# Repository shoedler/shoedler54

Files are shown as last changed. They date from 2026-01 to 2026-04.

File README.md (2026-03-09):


> Kailh Choc v2 Ice Creams, Taihao THTs

# shoedler54
A 54-key, column-staggered, ortholinear, wireless split keyboard, inspired by ZSA Voyager and silakka54.
Designed for Mx-spacing (18mm keycaps) and 1350 Choc v1 or v2 switches.

## Why?

This project came to life as I wanted to get up to speed with [ergogen.xyz](ergogen.xyz). The main goal of was to build a keyboard using solely the declarative ergogen paradigm - including making a case. As such, the only thing that was done outside of ergogen was to route the PCB and flip one case half in the slicer. That, as well as configuring the firmware (it'd be a nice extension to ergogen to generate the `.dtsi` file for ZMK automatically, but alas, that's not supported - yet).
Other things I've aimed for:
- Must be cheap, < $100 for a complete keyboard.
- Must be low profile, comparable to the ZSA Voyager.

## Impressions


> Carry case


> With optional MCU + battery cover


> Black version with Kailh Choc v2 Black Clouds, Repo-included 3D printed keycaps

---

## Bill of materials

For one complete board - e.g. two halves - you'll need:

- 2 Promicro NRF52840
- 54 1N4148W SOD-123 Diodes
- 54 Kailh Low-profile 1350 Hotswap Sockets
- 54 Keyswitches, Choc v1 or v2
- 54 1u (18mm) Keycaps, Choc v1 or v2 stems (I suggest to print the provided ones (Mx-stem e.g. Choc v2), or - if you want legends, the Taihao THTs)
- 2 EVQPUL02K Switches ($\to$ board reset button)
- 2 SSSS811101 Switches ($\to$ power switch)
- 2 801540 3.7v, 380mAh Batteries
  - or, 2 701535 3.7v, 350mAh
  - or, 2 501646 3.7v, 380mAh (these are too long (46mm) and require to be soldered to the JST pads, which I **do not recommend**!)
- 2 JST PH 2.0 THT Sockets

For the case you'll need:

- Obviously, the printed case files. See section about printing below.
- 10x M2x5 (or 6)mm flathead screws
- 10x M2x3mm Heat set inserts
- Optionally, some painters tape.

## Approximate cost

| What | Supplier | Comment | Price |
| --- | --- | --- | --- |
| 2 PCBs | JLCPCB | 5pcs. (min), including a hefty delivery fee to get to my location, $32 | ~$13 |
| 2 MCUs | AliExpress | Promicro NRF52840 | ~$4 |
| 54 Diodes | AliExpress | 1N4148W SOD-123 | ~$1 |
| 54 Kailh Low 1350 Sockets | AliExpress | Hotswap | $4 |
| 54 Keyswitches, Choc v1/v2 | AliExpress | pack of 70 | $25 |
| 54 1u Keycaps, Choc v1/v2 | AliExpress | pack of 60 | $15 |
| 2 Reset Switches | AliExpress | EVQPUL02K | ~$1 |
| 2 Power Switches | AliExpress | SSSS811101 | $1 |
| 2 Batteries | AliExpress | 801546, 380mAh | $8 |
| 2 JST PH 2.0 Sockets | AliExpress | | ~$1 |
> Prices as of january, 2026

Should result in ~$75 per completed keyboard. This does not include the case hardware and printed case files, but it's all you need to get a working keyboard. Also, the prices listed are adjusted to the amount of parts required.

> [!NOTE]
> You'd want to buy some parts in "bulk", like a strip of 100 diodes. Since you likely also have a minimum order quantity for the PCBs, it might make sense to buy two more MCUs and maybe some old keyswitches and caps to get another full keyboard out of the rest of the parts and still have one PCB for soldering mistakes left ;)

As alluded to in the BOM, a 3d printable model for a custom cap that fits this build is provided - more on that in the build guide.

## Build guide

### PCB manufacturing

> PCB related files are located in the `kicad` directory.

Assuming you have ordered the parts and don't want to route the PCB yourself, there's premade gerber archive located at `kicad/gerber.zip` which you can use. I've used JLCPCB, default settings (1.6mm two layer PCB) and with the black solder mask.

### Printing the case

> Case files are located in the `stl` directory.

I used a Babulab A1 mini and default slicer settings (Bambustudio). Everything was printed in their PLA Matte.

#### What do I need to print?

You'll need at least:

- 2x `shoedler54_switchplate_right.stl`, which is the plate that sits on the PCB and where the keyswitches are mounted into - I recommend using the provided 3mf files for that: `shoedler54_switchplate_left.3mf` and `shoedler54_switchplate_right.3mf`. That'll give you mirrored versions so you have the buildplate-finish texture on the same side for both halves.
- 2x `shoedler54_case_left.stl`, which is the case where the PCB gets mounted in - same story, use the provided 3mf files for that: `shoedler54_case_left.3mf` and `shoedler54_case_right.3mf`. That'll also give you mirrored versions for both halves with fuzzy skin. Theoretically, you don't **need** the case, but I strongly recommend it to provide a little bit of protection for the PCB. If you're working directly with the stl, then you'll have to mirror it. I suggest using the fuzzy skin setting (in Bambustudio: `Others > Special mode > Fuzzy skin`, use "Contour").

Optional:

- 2x `shoedler54_case_cover_right.stl`, which is a small cover for the MCU + battery. Use `shoedler54_case_cover_left.3mf` and `shoedler54_case_cover_right.3mf` for mirrored version. Same as with the case, if you're working with the stl directly you'll need to mirror this too.
- 1x `shoedler54_carry_case.stl`, which is a Go60-ish carry shell for the shoedler54. Use `shoedler54_carry_case.3mf` for a version with fuzzy skin. I did manage to print it without support, but there's a bit of luck involved.

### Printing the keycaps

> Keycap related files are located in the `scad` directory.

The caps require no supports if you place them on one of the fillets - they do however require good bed adhesion. This, just like the case, was also printed on a Bambulab A1 mini with PLA Matte. Also, like the case, I've provided a 3mf file to print 26 regular + 1 indexing (F/J keys on QWERTY) keys. If you have to use the stl directly:

- Use 0.12mm layer height (including the initial layer).
- Use a brim - if your slicer doesn't automatically generate it, add it manually.

> [!NOTE]
> The keycap was designed in [OpenSCAD](openscad.org). It's fully parametrized, so it's easy to adapt to your liking.

### Soldering

Since the PCB is reversible it can get confusing quick. All of the components **except the ProMicro and the JST connector** are soldered to the backside of each half.

1. Solder diodes, hotswap sockets, reset- and powerswitches on the backside of each half. **This is also the side were you bridge all of the solder-jumpers with solder** (8 for the Mcu, 2 for the Battery connector).
2. Direct-solder the ProMicro to the frontside of the PCB, along with the JST connector. (Pin Sockets are also an option for the mcu, if you want - it just makes the keyboard a bit thicker)

> [!CAUTION]
> Before you continue it's a good idea to verify that there's no short between the JSTs +/- terminal as well as the ProMicros VCC and GND.

I suggest to load the firmware next and check that everything works before assembly.

### Loading the ZMK firmware

> Firmware related files consist of: config/, boards/, zephyr/ directories, as well as the build.yml file and the GitHub Actions workflow in .github/workflows.build.yml

Get the latest firmware from https://github.com/shoelder/shoedler54/actions, select the latest run and scroll down to Artifacts - you'll be able to download the zip archive from there.

> [!NOTE]
> There'll be two .uf2 files per half in the zip archive - a `de-ch` and an `en` version. This refers to the keycode locale that's been used. I myself require a swiss locale, but, to make the default firmware more useful for more people, I've added an english version too. You can check the keymaps out in the `config/boards/shields/shoedler54` directory.

For each half:

1. Plug in the half to your device using a USB cable.
2. Press the reset button twice within 500ms - on my versions of the ProMicro, their red LED breaths gently once you've entered bootloader mode.
3. You'll see a `NICENANO` appear in your device tree. Simply drag and drop the **correct** firmware for the half your working on onto the mcu - it should eject itself automatically once the firmware is flashed.

> [!NOTE]
> If you run into trouble, there's also a `settings_reset` firmware provided in the archive. See [the ZMK troubleshooting guide](https://zmk.dev/docs/troubleshooting/connection-issues#reset-split-keyboard-procedure) on how to flash it.

### Assembly

1. Prep the cases by installing the heat set inserts.
2. Cover the bottom sides of the PCBs with tape (I used masking tape). Apply the first layer quite firmly, such that it follows the contours of the hotswap sockets. You'll want to make sure that you extend the tape over the edges of the PCB. Apply at least 3 layers. In my experience anything beyond 5 layers of standard painters tape yields no further improvements. Also, it gets thick quick.



3. Trace the PCB outline to the tape with a pen. Also, trace the screw holes.



4. Remove the tape, and cut out the shape - make sure to inset the cut about 2-3mm, so the tape is not visible when everything is assembled. For the screw holes, cut a ~5x5mm square. Apply the tape.



5. Assemble both halves.



6. Install the switches, caps and the battery. For the battery, I usually use a thin, clear double-sided tape. Done!



---

## Modifying the ergogen config

The whole point of using ergogen, is to easily adapt the PCB to your liking. So give it a go!
Modifying the config will force you to reroute the PCB again. Though fear not - using [Freerouting](www.freerouting.app) this literally takes a minute to do (including adding freerouting to KiCad), provided you have KiCad >=8 and JRE >= 17 for Freerouting already installed.

> [!NOTE]
> To add the Freerouting KiCad integration, just follow [this](https://github.com/freerouting/freerouting/blob/master/docs/integrations.md) official guide.

1. Paste `config.yml` located in `/ergogen` into [ergogen.xyz](ergogen.xyz) and download the `shoedler54.kicad_pcb` file.
2. Copy (and overwrite) `shoedler54.kicad_pcb` to the `kicad` directory of this repository *(this part is only required if you intend to keep the source of this repository up to date - e.g. if you forked this)*
3. Open the PCB in KiCad (Standalone PCB editor suffices) and click on `Tools > External Plugins > Freerouting`
4. Let it rip. In my experience, the defaults of Freerouting suffice.

> [!IMPORTANT]
> Back in KiCad, run the DRC in `Inspect > Design Rule Checker`. I usually right click `> Ignore all 'Footprint not found in libraries' violations` to ignore missing ceoloide footprint warnings. This might leave you with some warnings which you need to manually resolve. For example, i usually get "Track has unconnected end", which is easily resolved by deleting the stub.

5. `File > Plot... > Generate Drill Files`, name the folder "gerber", then press `Generate` and close that popup. Press `Plot` back in the plot dialog. Done!

## References

- Flatfootfox' detailed design guide: https://flatfootfox.com/ergogen-part1-units-points/
- nickcoutsos Keymap-editor: https://nickcoutsos.github.io/keymap-editor/
- nickcoutsos Keymap-layout-tools: https://nickcoutsos.github.io/keymap-layout-tools/
- Joel Spadins zmk-locale-generator for the de-swiss keycode header: https://github.com/joelspadin/zmk-locale-generator
- ZMK guide on how to add a new shield: https://zmk.dev/docs/development/hardware-integration/new-shield
- More of my keyboards:
  - effiddy - a 50-key wireless split, inspired by totem: https://github.com/shoedler/effiddy

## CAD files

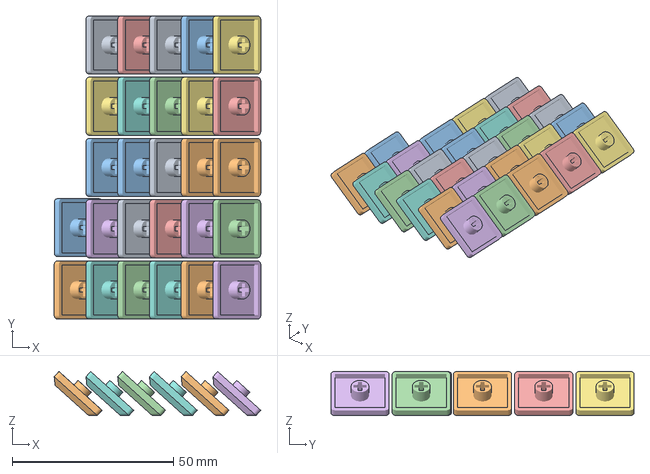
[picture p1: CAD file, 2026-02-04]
scad/keycap-26-1indexed.3mf
64.1 x 94.0 x 13.7 mm
keycap.stl x 26
keycap_homing.stl

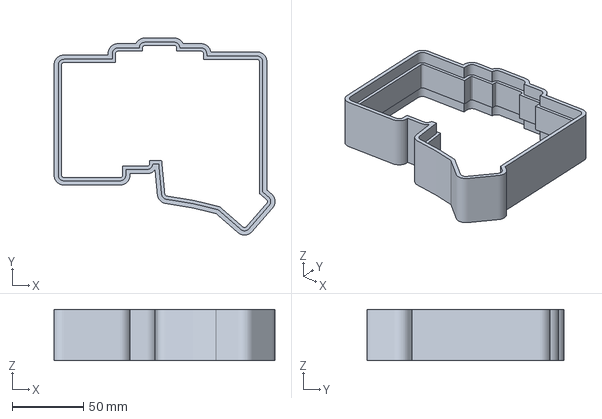
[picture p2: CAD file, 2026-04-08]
stl/shoedler54_carry_case.3mf
155.5 x 138.7 x 36.0 mm

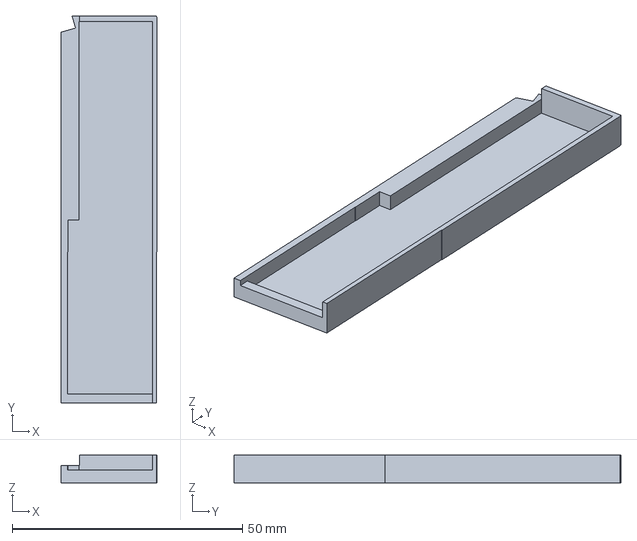
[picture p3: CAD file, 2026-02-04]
stl/shoedler54_case_cover_left.3mf
20.8 x 84.0 x 6.00 mm

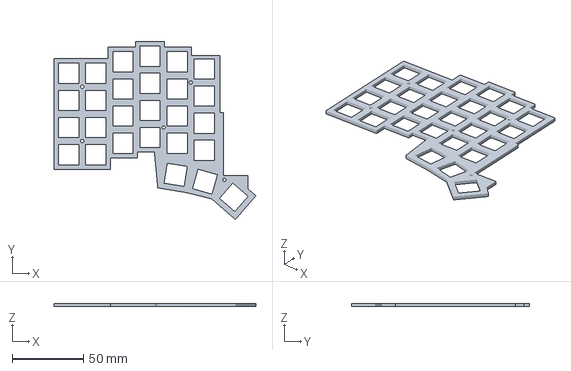
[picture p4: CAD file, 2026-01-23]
stl/shoedler54_case_switchplate_left.3mf
141.5 x 124.7 x 2.20 mm

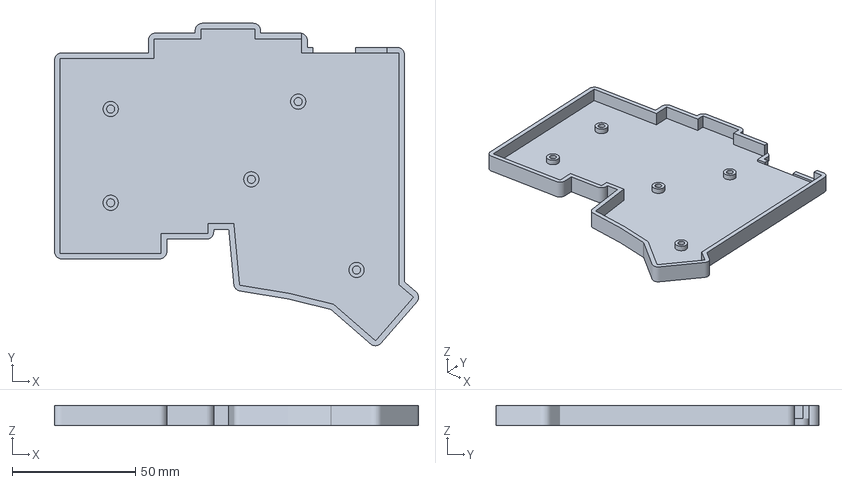
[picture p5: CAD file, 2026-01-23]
stl/shoedler54_case_left.3mf
147.5 x 130.7 x 8.30 mm

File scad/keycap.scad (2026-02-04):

/*
  Low profile Keycap for MX stems inspired by the ZSA Voyager and Taihao THTs.
  Units: mm

  This has been tested with an FDM 3D-Printer (Bambulab A1 mini) with PLA Matte.
  Requires no supports if you print with a brim and place it on one of its fillets 
  (at an angle)
  0.12mm layer-height (incl. initial layer).

  Notes / modeling choices:
  - Outer body is a two-stage extrusion: straight walls up to `side_fillet_start_z`,
    then a gentle taper toward the top “inset” footprint.
  - The “touch surface” concavity is approximated by subtracting a cylinder-shaped dish,
    with ~`dish_depth` sag at the center.
  - MX cross hole is a 2D plus that gets filleted using offset(r) then offset(-r)
*/

$fn = 96;

// -------------------------
// Parameters (grouped)
// -------------------------
/* Keycap footprint */
cap_w            = 18;     // X (use different values for oblong)
cap_h            = 18;     // Y
cap_corner_r     = 1.2;    // outer corner radius

/* Vertical dimensions */
cap_thickness        = 4.0;   // total height of cap body (cap bottom to top exterior)
wall_thickness       = 1.2;   // keycap underside cavity walls
underside_pocket_z   = 1.9;   // cavity depth from bottom (inside hollow depth)
side_fillet_start_z  = 2.2;   // z where outer “inset/taper” begins

/* Top inset / touch surface shaping */
inset_lr         = 2.0;   // inset on left/right at the very top (X border)
inset_tb         = 2.0;   // inset on top/bottom at the very top (Y border) (your 2mm->1mm feel)
dish_depth       = 1.0;   // concavity depth at center (approx)
dish_span_scale  = 0.95;  // how wide the dish influences (0..1), smaller = more localized

/* Stem (outer post) */
stem_outer_d     = 5.5;   // outer cylinder diameter
stem_total_len   = 3.8;   // total stem length up to the internal “roof” it attaches to
stem_protrude    = 1.9;   // how much stem sticks out below the keycap bottom (also equals pocket depth)

/* MX cross hole - these values are not to spec, but rather to print nicely. */
mx_plus_size     = 4.1;   // overall height/width of plus (across opposite ends)
mx_leg_thick     = 1.25;  // thickness of each leg
mx_inner_fillet  = 0.3;   // fillet radius for inside corners

/* Homing indicator (optional) */
enable_homing    = false;  // set true for F/J
homing_len       = 5.0;   // bar length (X)
homing_w         = 0.7;   // bar width (Y)
homing_h         = 0.5;   // bar height (Z)
homing_offset_x  = -2;    // move bump toward you (negative X) like typical F/J
homing_offset_z  = 1.1;   // move bump into/away from the keycap

// -------------------------
// Helpers
// -------------------------
module rounded_rect_2d(w, h, r) {
  r2 = min(r, min(w,h)/2);
  offset(r=r2) square([w-2*r2, h-2*r2], center=true);
}

module mx_plus_2d(size, leg, fillet_r) {
  // Sharp plus first
  union() {
    union() {
      square([leg, size], center=true);
      square([size, leg], center=true);
    }

    // Add material only in the 4 re-entrant (inside) corners
    // (these are at ±leg/2, ±leg/2). This won’t touch the 8 outer corners.
    for (sx = [-1, 1], sy = [-1, 1]) {
      translate([sx*leg/2, sy*leg/2]) 
        rotate([0,0,45])
          square(fillet_r, center=true);
    }
  }
}


// capsule-ish bar for homing (2D), then extrude
module capsule_2d(len, w) {
  // hull of two circles to make a capsule
  hull() {
    translate([-(len/2 - w/2), 0]) circle(d=w);
    translate([ +(len/2 - w/2), 0]) circle(d=w);
  }
}

// -------------------------
// Main model
// -------------------------
module keycap_body() {
  // bottom footprint
  base_w = cap_w;
  base_h = cap_h;

  // top footprint (inset)
  top_w  = max(0.1, cap_w - 2*inset_tb);
  top_h  = max(0.1, cap_h - 2*inset_lr);

  // scale factors for the upper taper
  sx = top_w / base_w;
  sy = top_h / base_h;

  lower_h = min(side_fillet_start_z, cap_thickness);
  upper_h = max(0, cap_thickness - lower_h);

  union() {
    // lower straight section
    linear_extrude(height=lower_h)
      rounded_rect_2d(base_w, base_h, cap_corner_r);

    // upper tapered section
    if (upper_h > 0.0001)
      translate([0,0,lower_h])
        linear_extrude(height=upper_h, scale=[sx, sy])
          rounded_rect_2d(base_w, base_h, cap_corner_r);
  }
}

module underside_pocket() {
  // cavity is a rounded rectangle inset by wall thickness
  inner_w = cap_w - 2*wall_thickness;
  inner_h = cap_h - 2*wall_thickness;
  inner_r = max(0, cap_corner_r - wall_thickness);

  // pocket cut from the bottom upward
  translate([0,0,0])
    linear_extrude(height=underside_pocket_z + 0.02)  // tiny extra to avoid z-fighting
      rounded_rect_2d(inner_w, inner_h, inner_r);
}

// concave dish made with a cylinder (axis along X)
module concave_dish_cut() {
  // cylinder gives curvature in Y, leaving X mostly "flat"
  top_h = max(0.1, cap_h - 2*inset_lr);

  a = dish_span_scale * top_h / 2; // half-chord in Y
  h = dish_depth;                  // sagitta (depth)

  // R = (a^2 + h^2)/(2h)
  R = (a*a + h*h) / (2*h);

  // place cylinder so that it cuts depth ~h at center on the top surface.
  // for a cylinder, the surface at y=0 sits at z = zc - R, so set that to cap_thickness - h.
  zc = (cap_thickness - h) + R;

  intersection() {
    translate([0,0,zc])
      rotate([0,90,0])  // axis along X
        cylinder(r=R, h=cap_w*3, center=true);

    // bounding box around the top region
    translate([0,0,cap_thickness - 3*h])
      cube([cap_w*2, cap_h*2, 6*h], center=true);
  }
}


// stem placement and extrude it to connect to keycap hull
module stem_post_with_mx_hole() {
  // force stem top to meet the "roof" (top of the underside pocket) at z = underside_pocket_z
  z1 = underside_pocket_z;
  z0 = z1 - stem_total_len;

  difference() {
    translate([0,0,z0])
      cylinder(d=stem_outer_d, h=stem_total_len);

    translate([0,0,z0 - 0.2])
      linear_extrude(height=stem_total_len + 0.4)
        mx_plus_2d(mx_plus_size, mx_leg_thick, mx_inner_fillet);
  }
}


module homing_bump() {
  if (enable_homing) {
    // put it on the top surface, slightly sunk into the dish cut region.
    translate([homing_offset_x, 0, cap_thickness - homing_offset_z])
      rotate([0, 0, 90])
      linear_extrude(height=homing_h)
        capsule_2d(homing_len, homing_w);
  }
}

module low_profile_xm_keycap() {
    union() {
      difference() {
        // main cap shell (solid, then we hollow it)
        keycap_body();
        
        // underside hollow pocket
        underside_pocket();

        // concave touch dish (top shaping)
        concave_dish_cut();
      }
      // stem post attached to the inside roof (top of pocket)
      stem_post_with_mx_hole();

      // optional homing bump 
      homing_bump();
    }
  
}

// -------------------------
// Render
// -------------------------
low_profile_xm_keycap();

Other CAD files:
stl/shoedler54_case_cover_right.3mf
stl/shoedler54_case_switchplate_right.3mf
stl/shoedler54_case_right.3mf
stl/shoedler54_carry_case.stl
stl/shoedler54_case_cover_right.stl
stl/shoedler54_case_left.stl
stl/shoedler54_case_switchplate_right.stl

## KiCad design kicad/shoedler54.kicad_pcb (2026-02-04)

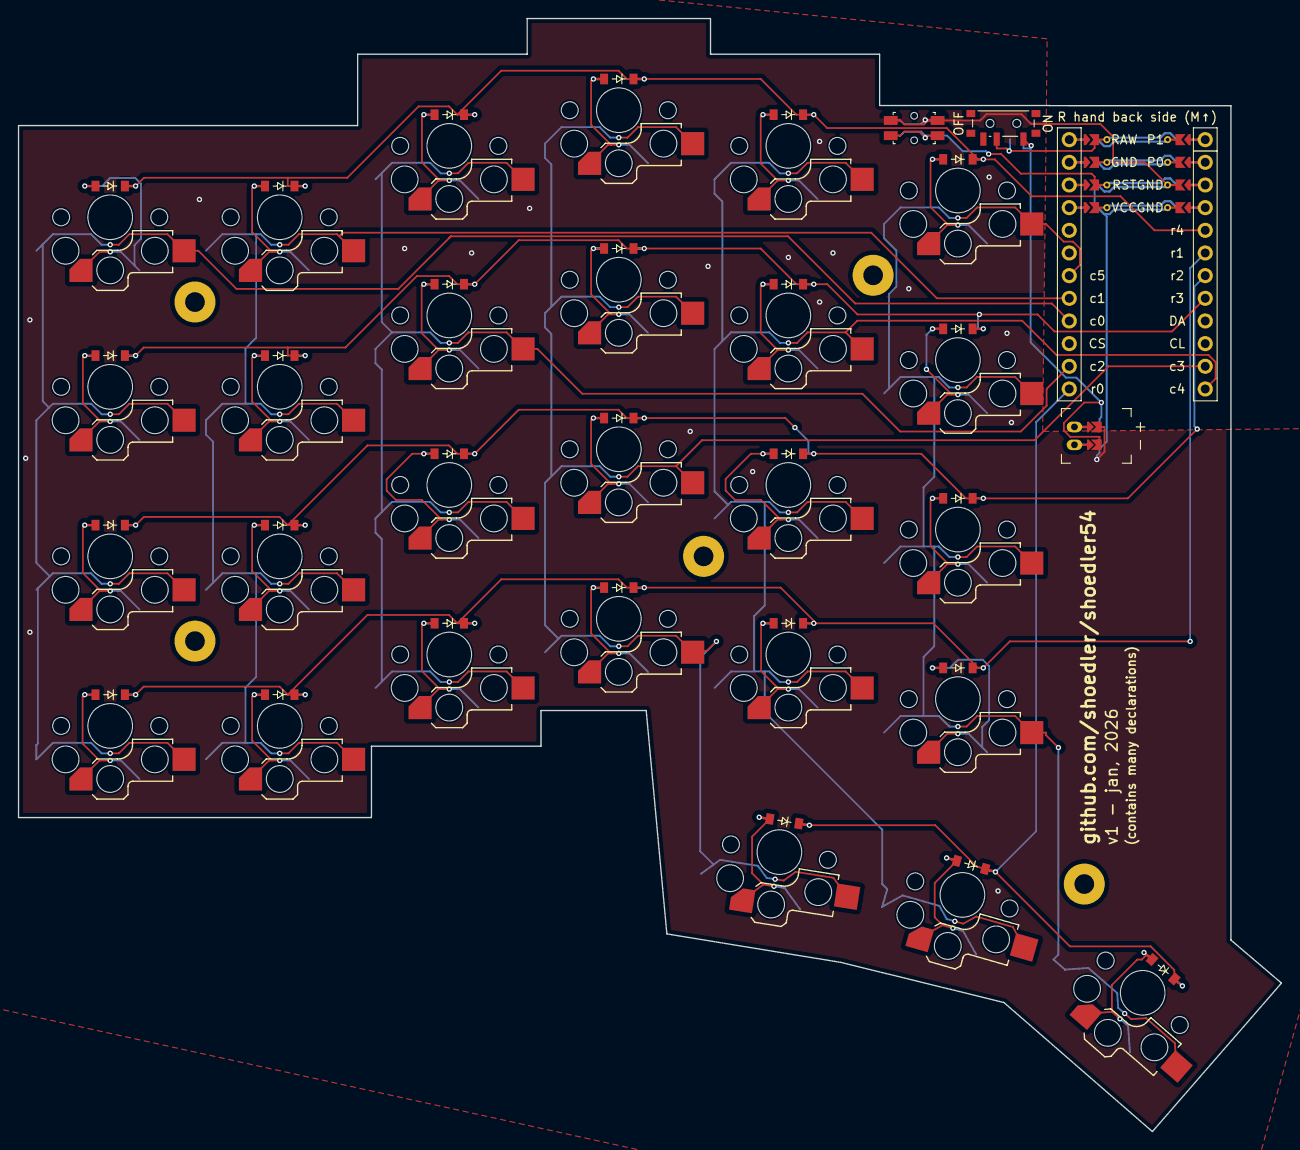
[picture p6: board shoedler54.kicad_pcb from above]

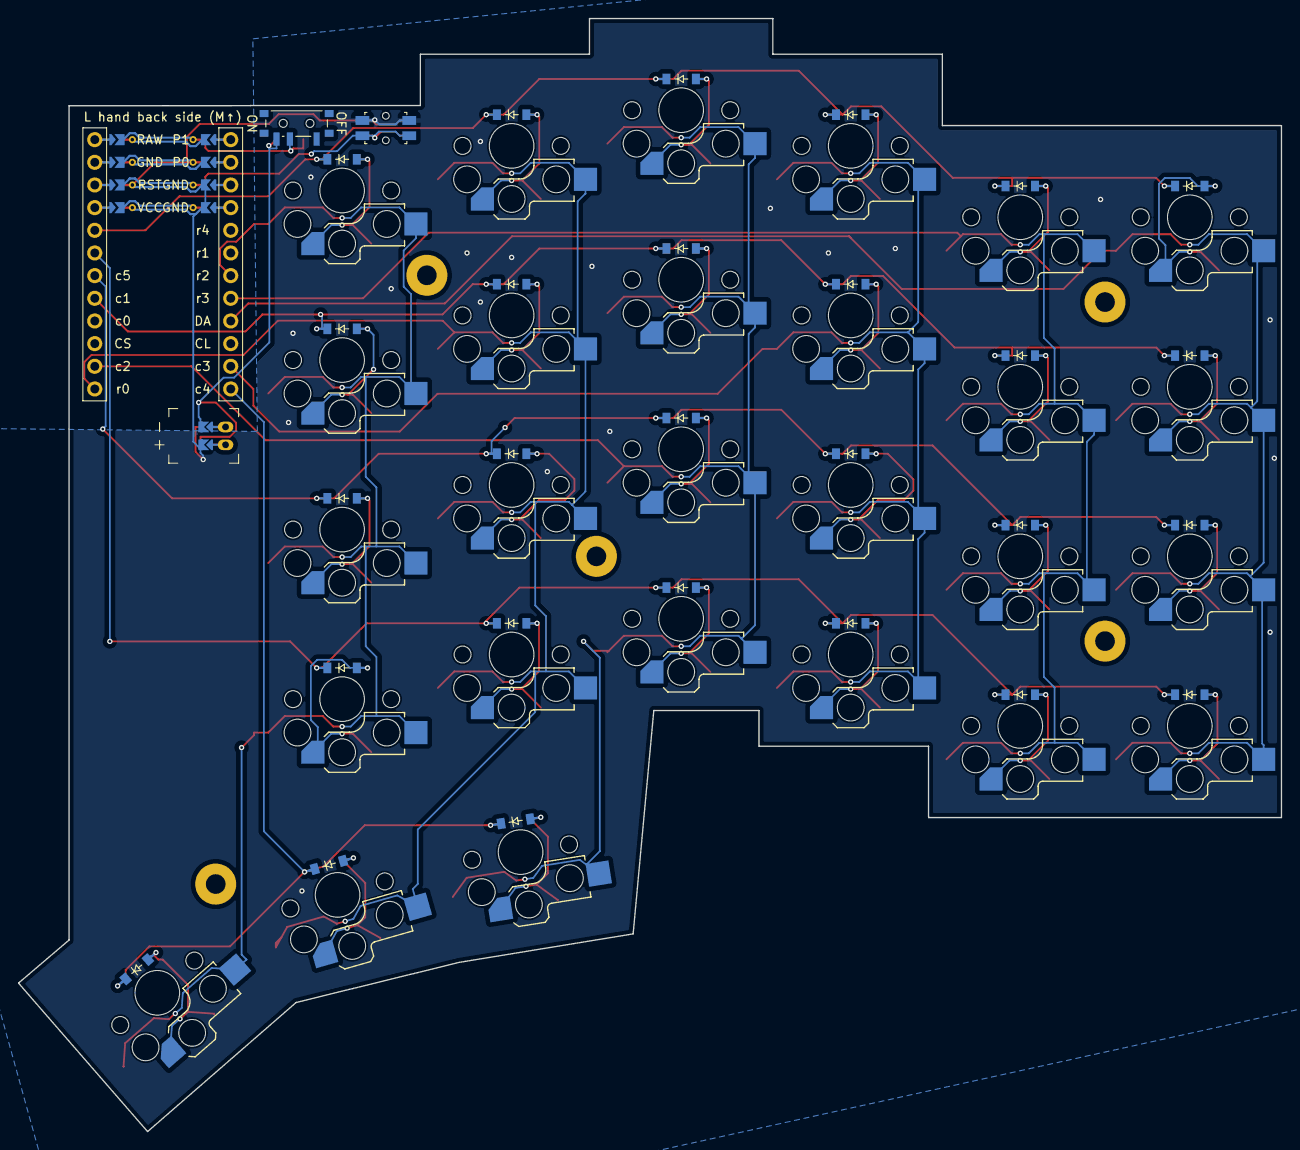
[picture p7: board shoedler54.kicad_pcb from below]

Board: 2 copper layers, 141.5 x 124.7 mm, 63 parts (27 on the bottom side), 44 nets.

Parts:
D1, D2, D3, D4, D5, D6, D7, D8, D9, D10, D11, D12, D13, D14, D15, D16, D17, D18, D19, D20, D21, D22, D23, D24, D25, D26, D27: diode_tht_sod123
JST1: battery_connector_jst_ph_2
MCU1: mcu_supermini_nrf52840
MH1, MH2, MH3, MH4, MH5: mounting_hole_npth
PWR1: power_switch_smd_side
RST1: reset_switch_smd_side
S1, S2, S3, S4, S5, S6, S7, S8, S9, S10, S11, S12, S13, S14, S15, S16, S17, S18, S19, S20, S21, S22, S23, S24, S25, S26, S27: switch_choc_v1_v2

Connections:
BAT_P: JST1.1, PWR1.1, PWR1.3
GND: JST1.2, MCU1.103, MCU1.104, MCU1.123, RST1.1, RST1.3
JST1_1: JST1.11, JST1.21, JST1.31
JST1_2: JST1.12, JST1.22, JST1.32
RAW: MCU1.124, PWR1.2
RST: MCU1.122, RST1.2, RST1.4
c0: MCU1.16, S1.2, S2.2, S3.2, S4.2
c0_r1: D1.2, S1.1
c0_r2: D2.2, S2.1
c0_r3: D3.2, S3.1
c0_r4: D4.2, S4.1
c1: MCU1.17, S5.2, S6.2, S7.2, S8.2
c1_r1: D5.2, S5.1
c1_r2: D6.2, S6.1
c1_r3: D7.2, S7.1
c1_r4: D8.2, S8.1
c2: MCU1.14, S9.2, S10.2, S11.2, S12.2
c2_r1: D9.2, S9.1
c2_r2: D10.2, S10.1
c2_r3: D11.2, S11.1
c2_r4: D12.2, S12.1
c3: MCU1.11, S13.2, S14.2, S15.2, S16.2, S25.2
c3_r0: D25.2, S25.1
c3_r1: D13.2, S13.1
c3_r2: D14.2, S14.1
c3_r3: D15.2, S15.1
c3_r4: D16.2, S16.1
c4: MCU1.12, S17.2, S18.2, S19.2, S20.2, S26.2
c4_r0: D26.2, S26.1
c4_r1: D17.2, S17.1
c4_r2: D18.2, S18.1
c4_r3: D19.2, S19.1
c4_r4: D20.2, S20.1
c5: MCU1.18, S21.2, S22.2, S23.2, S24.2, S27.2
c5_r0: D27.2, S27.1
c5_r1: D21.2, S21.1
c5_r2: D22.2, S22.1
c5_r3: D23.2, S23.1
c5_r4: D24.2, S24.1
r0: D25.1, D26.1, D27.1, MCU1.13
r1: D1.1, D5.1, D9.1, D13.1, D17.1, D21.1, MCU1.6
r2: D2.1, D6.1, D10.1, D14.1, D18.1, D22.1, MCU1.7
r3: D3.1, D7.1, D11.1, D15.1, D19.1, D23.1, MCU1.8
r4: D4.1, D8.1, D12.1, D16.1, D20.1, D24.1, MCU1.5

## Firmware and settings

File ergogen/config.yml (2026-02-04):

meta:
  engine: 4.2.0

units:
  shared_mcu_w: 17.78 # ProMicro width
  shared_mcu_h: 33 # ProMicro height

  outline_ol_pad: 1.5 # Outline padding (PCB fab constraints)
  outline_keycap_size: 18
  outline_keycap_fillet: 1

  pcb_screw_hole_size: 4.6
  pcb_screw_drill: 2.2

  case_switchplate_d: 2.2 # 2.2mm thickness for Chocs
  case_bottom_t: 2 # Case (bottom) thickness
  case_wall_rise: 2.5
  case_plate_clearance: 1.6
  case_io_lip_drop: 1.5
  case_io_mask_h: 10
  case_switchplate_size: 14.2 # 0.2mm padding for 3D printing
  case_screw_insert_r: 1.2
  case_screw_hole_r: 1.65
  case_screw_standoff_r: 3.1
  case_insert_lip_h: 1
  case_cover_t: 1
  case_cover_wall_t: 5
  case_usb_c_t: 3.2 # USB-C thickness

points:
  key.spacing: U
  key.tags: key
  zones:
    matrix:
      anchor:
        shift: [150, -150] # Fix KiCad placement
      columns:
        c0: # Outer
        c1: # Pinky
        c2: # Ring
          key.stagger: 8
        c3: # Middle
          key.stagger: 4
        c4: # Index
          key.stagger: -4
        c5: # Inner
          key.stagger: -5
      rows:
        r1: # Bottom
        r2: # Home
        r3: # Above
        r4: # Nums

    thumb:
      anchor:
        ref: matrix_c5_r1
        shift: [-1.05*U, -0.9*U]
      columns:
        c3: # Thumb-outer
          key.splay: -9
        c4: # Thumb-middle
          key.spread: 20
          key.splay: -7
          key.origin: [-12, -9]
        c5: # Thumb-inner
          key.spread: 20
          key.splay: -25
          key.origin: [-10, -8]
      rows:
        r0: # Thumb

    mcu:
      key.tags:
        - helper
      anchor:
        - ref: matrix_c5_r4
          shift: [u/2+18/2+1.6, u/2-shared_mcu_h/2]

    screw_1:
      key.tags:
        - helper
        - screw
      anchor:
        aggregate.parts:
          - ref: matrix_c0_r4
          - ref: matrix_c0_r3
          - ref: matrix_c1_r4
          - ref: matrix_c1_r3

    screw_2:
      key.tags:
        - helper
        - screw
      anchor:
        aggregate.parts:
          - ref: matrix_c5_r4
          - ref: matrix_c5_r3
          - ref: matrix_c4_r4
          - ref: matrix_c4_r3
        shift: [0, -2.5]

    screw_3:
      key.tags:
        - helper
        - screw
      anchor:
        aggregate.parts:
          - ref: matrix_c0_r1
          - ref: matrix_c0_r2
          - ref: matrix_c1_r1
          - ref: matrix_c1_r2

    screw_4:
      key.tags:
        - helper
        - screw
      anchor:
        aggregate.parts:
          - ref: thumb_c4_r0
          - ref: thumb_c5_r0
          - ref: matrix_c5_r1
        shift: [7.5, 0]

    screw_5:
      key.tags:
        - helper
        - screw
      anchor:
        aggregate.parts:
          - ref: matrix_c4_r2
          - ref: matrix_c4_r1
          - ref: matrix_c3_r2
          - ref: matrix_c3_r1
        shift: [0, -0.5]

outlines:
  shoedler54: # Main PCB outline and key padding.
    - where: [key]
      what: rectangle
      size: [U+outline_ol_pad, U+outline_ol_pad]
    - where: [mcu]
      what: rectangle
      size: [18+outline_ol_pad, shared_mcu_h]
    - what: rectangle # Removes the [key] padding left of the mcu
      where: matrix_c5_r4 # (where the switches are)
      size: [U+outline_ol_pad, U]
      adjust.shift: [outline_ol_pad, U]
      operation: subtract
    - what: polygon # Bridge between matrix and thumb cluster.
      points:
        - ref: matrix_c2_r1
          shift: [U/2, -U/2]
        - ref: matrix_c3_r1
          shift: [-U/2, -U/2]
        - ref: matrix_c3_r1
          shift: [3, -U/2]
        - ref: thumb_c3_r0
          shift: [-U/2-outline_ol_pad, -U/2-outline_ol_pad]
        - ref: thumb_c3_r0
          shift: [-U/2-outline_ol_pad, -U/2-outline_ol_pad]
        - ref: thumb_c4_r0
          shift: [-U/2-outline_ol_pad, -U/2-outline_ol_pad]
        - ref: thumb_c5_r0
          shift: [-U/2-outline_ol_pad, -U/2-outline_ol_pad]
        - ref: thumb_c5_r0
          shift: [U/2+outline_ol_pad, -U/2-outline_ol_pad]
        - ref: thumb_c5_r0
          shift: [U/2+outline_ol_pad, U/2+outline_ol_pad]
        - ref: mcu
          shift: [18/2+outline_ol_pad, -77]
        - ref: mcu
          shift: [18/2+outline_ol_pad, shared_mcu_h/2]
        - ref: matrix_c5_r4
          shift: [-U/2, U/2]
        - ref: matrix_c2_r1
          shift: [-U/2, -U/2]

  _pcb_keycaps:
    - where: [key]
      what: rectangle
      size: outline_keycap_size
      fillet: outline_keycap_fillet
    - where: [thumb]
      what: rectangle
      size: outline_keycap_size
      fillet: outline_keycap_fillet

  _pcb_mcu:
    - where: [mcu]
      what: rectangle
      size: [shared_mcu_w, shared_mcu_h]
    - where: [mcu]
      what: rectangle
      size: [8.94, 7.35]
      operation: stack
      adjust.shift: [0, shared_mcu_h/2-7.35/2+0.7]

  _pcb_screws:
    - where: [screw]
      what: circle
      radius: 4.3/2
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

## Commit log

2026-01-08 Enhance ergogen.yml for KiCad integration
2026-01-08 Move to local ergogen
    [left.dxf, left.kicad_pcb, preview.dxf]
2026-01-09 Removes output, fixes row/col net
    [left.dxf, left.kicad_pcb, preview.dxf]
2026-01-09 Revise ergogen, start pcb tracing
    [shoedler54.kicad_pcb]
2026-01-14 Adds initial case def
2026-01-14 Adds v2 for v1 prototype findings
2026-01-15 Updates README, makes v1 deprecated, removes ceoloide footprint dependency
2026-01-15 Moves deprecates/outdates v1 files - currently no v2 files exists, as there might be more findings
    [shoedler54-B_Cu.gbr, shoedler54-B_Mask.gbr, shoedler54-B_Paste.gbr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]
2026-01-21 Updates README and adds case to ergogen config (left only)
2026-01-21 Removes deprecated files and adds new PCB and case files
    [shoedler54-B_Cu.gbr, shoedler54-B_Mask.gbr, shoedler54-B_Paste.gbr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]
2026-01-23 Updates case files
    [shoedler54_case_key_plate_left.3mf, shoedler54_case_key_plate_right.3mf, shoedler54_case_left.3mf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]
2026-01-24 Updates keymap for de-CH locale
2026-01-25 Adds keycap files
    [keycap-26-1indexed.3mf, keycap.3mf, keycap.scad]
2026-01-25 Fixes keycap indexing location
    [keycap-26-1indexed.3mf, keycap.scad]
2026-01-25 Adds en keymap - just de-ch isn't useful for many people. lol.
2026-01-25 Moves keymap files
    [keycap.3mf]
2026-01-26 Adds bt bindings to de-ch keymap
2026-02-04 Fixes PCB silkscreen text, as JLCPCB fears having ergogen.xyz on it will trouble the customs paw patrol. Also made GND fill zones better by adding some vias.
    [shoedler54.kicad_pcb]
2026-02-04 Refactors ergogen config (Outputs are unaffected), renames printables, updates README accordingly.
    [shoedler54_carry_case.3mf, shoedler54_carry_case.stl, shoedler54_case_cover_left.3mf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]
2026-02-04 Updates keycap and its printfile to better match a similar off the shelf cap...
    [keycap-26-1indexed.3mf, keycap.scad]
2026-04-08 Adds supports to carry case 3mf
    [shoedler54_carry_case.3mf]
